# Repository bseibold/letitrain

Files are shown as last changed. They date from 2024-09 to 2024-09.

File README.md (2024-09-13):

# Let it rain

An ESP32 board intended for use with TL-136 level sensors

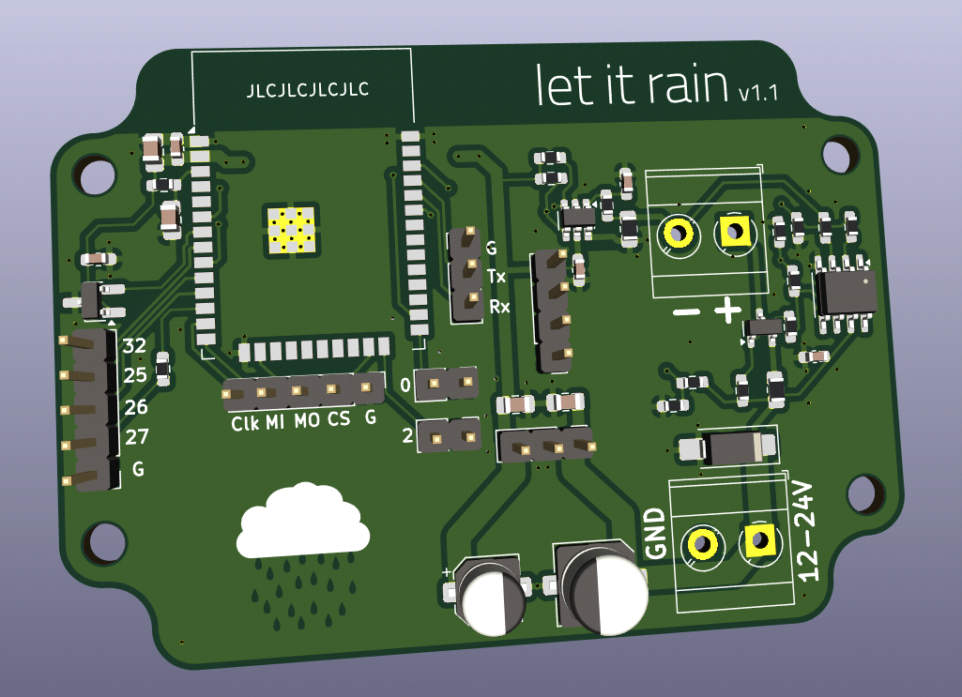
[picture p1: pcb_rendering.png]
Rendering of the PCB


## Status

Version 1 was built and is running well.

## Description

The sensor officially requires 24V, but in practice it runs well down to about 7V.
An op-amp is used to limit the current through the sensor and protect the ADC in case
of a short-circuit. The bias current of the op-amp has a small but measureable effect,
however the voltage measured by the ADC is still very linear to the current through the
sensor.

## Software

The board can be used with ESPHome, see [esphome.yaml](esphome.yaml) for an example configuration.

## BOM

 - 1x TL-136 differential pressure level sensor
 - 1x ESP32-WROOM-32x, can be any variant with the same footprint
 - 1x MCP3421 ADC converter
 - 1x OP07 Operational Amplifier
 - 1x MCP9700B temperature sensor (optional)
 - 1x DC-DC module with 780x compatible pins and 3.3V output. Must support 12-18V input

 - MLCC capacitors 0603, X5R or X7R, at least 6.3V
   - 5x 100nF (C1, C2, C3, C5, C6)
   - 1x 1µF (C2)
   - 2x 10µF (C4, C9)
 - MLCC capacitors 0603, X5R or X7R, at least 25V (better 50V)
   - 1x 100nF (C7)
   - 1x 1µF (C8)
 - 1x Polymer capacitor 5.0mm, at least 6.3V, 22µF (C10)
 - 1x Polymer capacitor 6.3mm, at least 25V (better 50V), 10µF (C11)
 - 1x Bidirectional TSV diode, SMA, voltage slightly above max. supply voltage (D1, optional)
 - 1x Pin header 0,1" 1x3 Pins (J3)
 - 1x BSS84 P-Channel Enhancement MOSFET (Q1)
 - 8x Resistor 0603, 10kOhm (R1, R3, R4, R9, R10, R11, R12, R15)
 - 2x Resistor 0603, 47kOhm (R2, R13)
 - 3x Resistor 0603, 1kOhm (R5, R6, R7)
 - 1x Resistor 0805, 100Ohm, high precision (R8)
 - 1x Resistor 0805, 33Ohm (R14)

Optional pin headers are omitted. They are intended for later reuse of spare PCBs.

The enclosure is an RL6115 from Hammond Manufacturing.

## Changelog

### Version 1.1

- Made more room for DC-DC module, it was a tight fit next to the capacitors
- Rotated TSV diode so that silkscreen is correct for unidirectional diodes
- Changed temperature sensor from MCP9701 to MCP9700B, changed footprint from SC70-5 to SOT23-3
- Some cosmetic fixes
- Marked optional stuff as DNP

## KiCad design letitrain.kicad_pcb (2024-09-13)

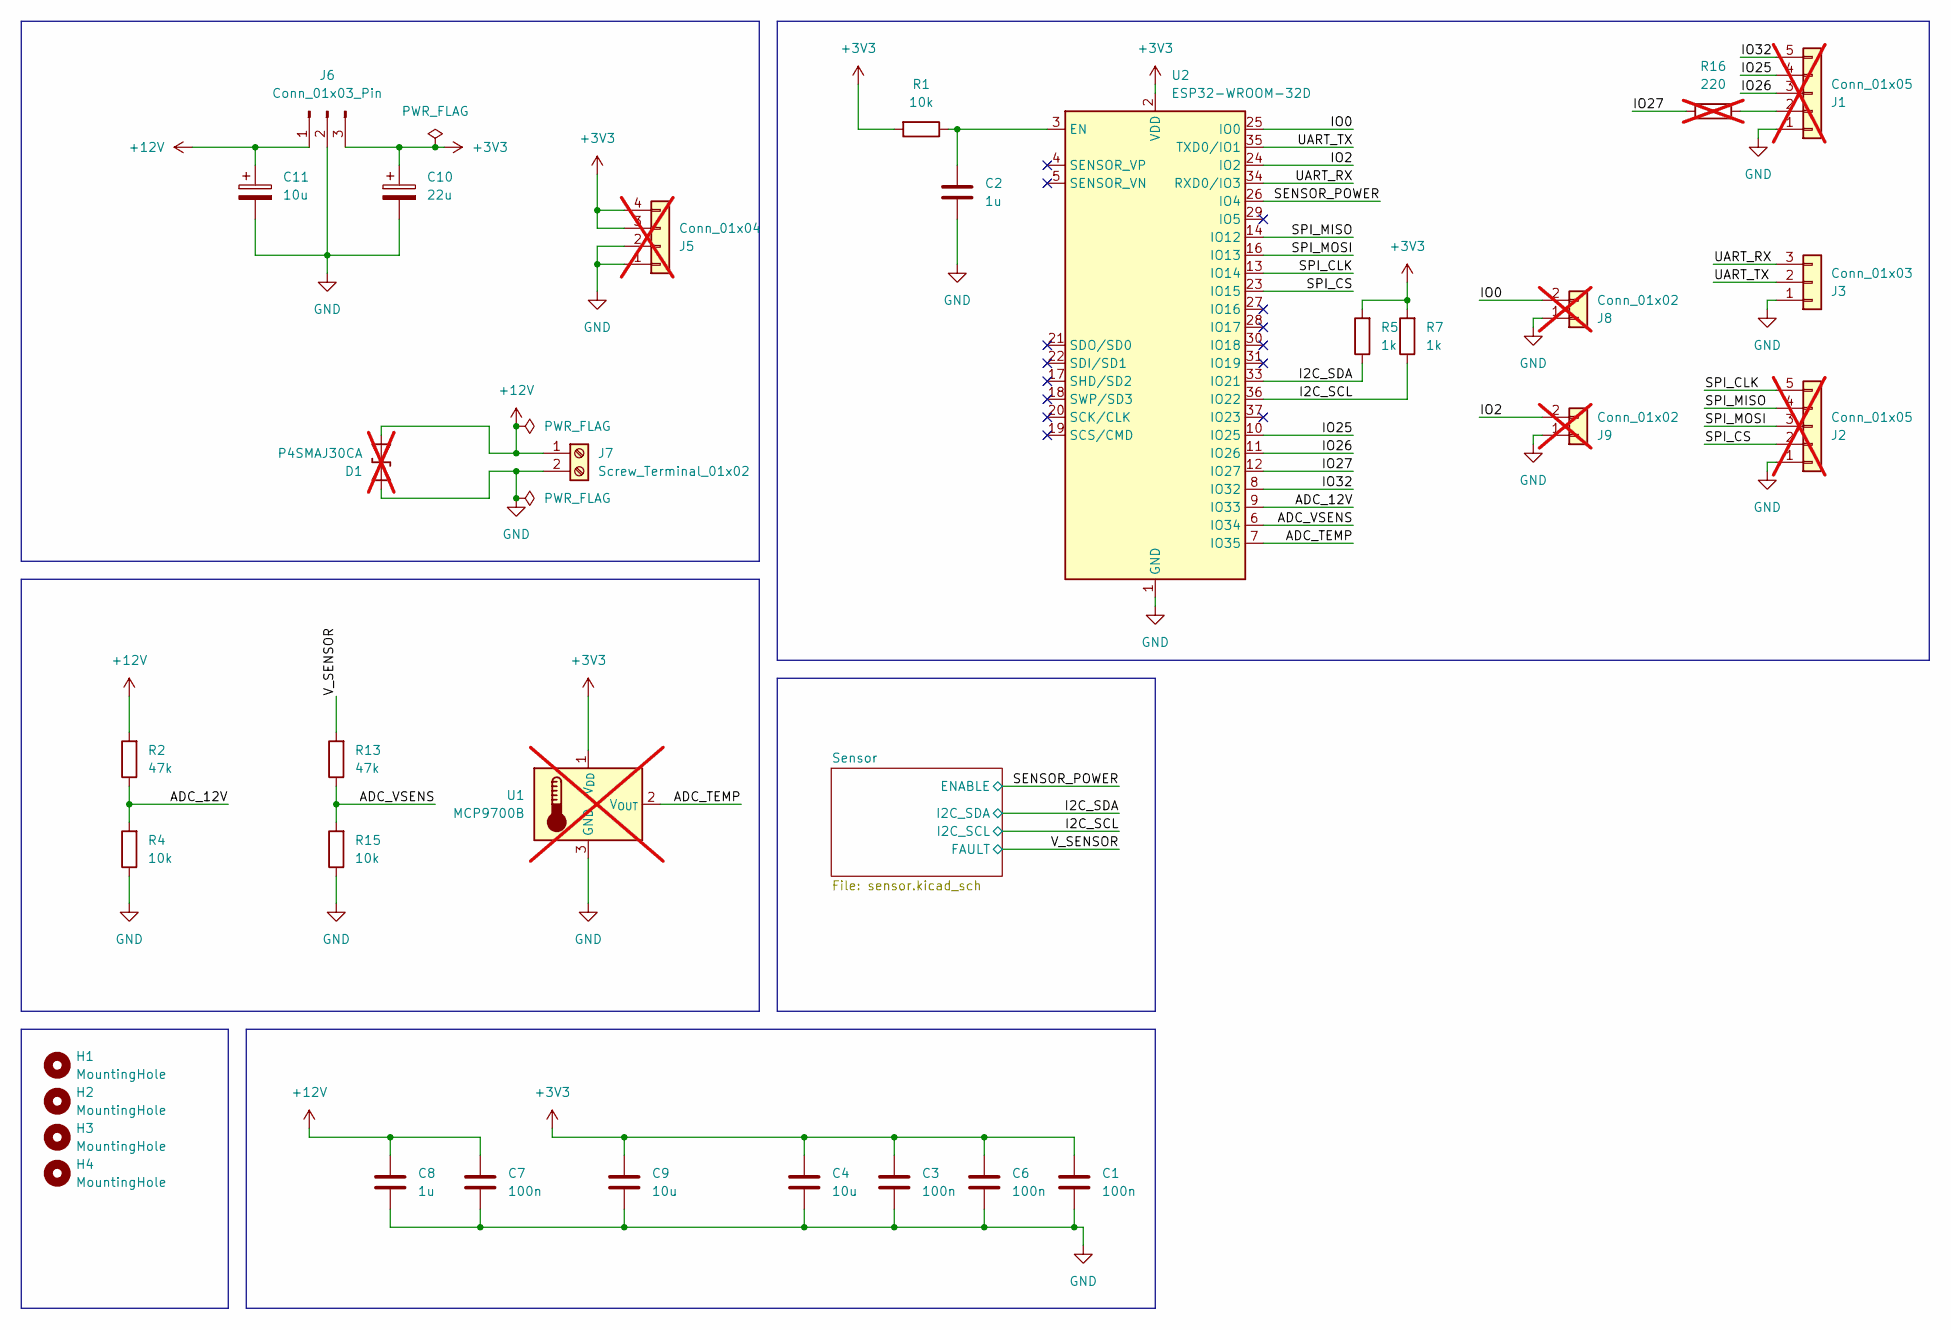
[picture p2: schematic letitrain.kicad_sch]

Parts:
C1, C3, C6, C7: 100n; C_0603_1608Metric_Pad1.08x0.95mm_HandSolder
C2, C8: 1u; C_0805_2012Metric_Pad1.18x1.45mm_HandSolder
C4, C9: 10u; C_0805_2012Metric_Pad1.18x1.45mm_HandSolder
C10: 22u; CP_Elec_5x5.8
C11: 10u; CP_Elec_6.3x5.8
D1: P4SMAJ30CA; D_SMA_Handsoldering; not fitted
H1, H2, H3, H4: MountingHole; MountingHole_3.2mm_M3
J1, J2: Conn_01x05; PinHeader_1x05_P2.54mm_Vertical; not fitted
J3: Conn_01x03; PinHeader_1x03_P2.54mm_Vertical
J5: Conn_01x04; PinHeader_1x04_P2.54mm_Vertical; not fitted
J6: Conn_01x03_Pin; PinHeader_1x03_P2.54mm_Vertical
J7: Screw_Terminal_01x02; TerminalBlock_MetzConnect_Type073_RT02602HBLU_1x02_P5.08mm_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
J8, J9: Conn_01x02; PinHeader_1x02_P2.54mm_Vertical; not fitted
R1, R4, R15: 10k; R_0603_1608Metric_Pad0.98x0.95mm_HandSolder
R2, R13: 47k; R_0603_1608Metric_Pad0.98x0.95mm_HandSolder
R5, R7: 1k; R_0603_1608Metric_Pad0.98x0.95mm_HandSolder
R16: 220; R_0603_1608Metric_Pad0.98x0.95mm_HandSolder; not fitted
U1: MCP9700B; SOT-23_Handsoldering; not fitted
U2: ESP32-WROOM-32D

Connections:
+3V3: C1.1, C3.1, C4.1, C6.1, C9.1, C10.1, J5.3, J5.4, J6.3, R1.2, R5.2, R7.2, U1.1 (V_{DD}), U2.2 (VDD); also elsewhere on the board
+12V: C7.1, C8.1, C11.1, D1.1 (A1), J6.1, J7.1, R2.2; also elsewhere on the board
/ADC_12V: R2.1, R4.2, U2.9 (IO33)
/ADC_TEMP: U1.2 (V_{OUT}), U2.7 (IO35)
/ADC_VSENS: R13.1, R15.2, U2.6 (IO34)
/I2C_SCL: R7.1, U2.36 (IO22); also elsewhere on the board
/I2C_SDA: R5.1, U2.33 (IO21); also elsewhere on the board
/IO0: J8.2, U2.25 (IO0)
/IO2: J9.2, U2.24 (IO2)
/IO25: J1.4, U2.10 (IO25)
/IO26: J1.3, U2.11 (IO26)
/IO27: R16.2, U2.12 (IO27)
/IO32: J1.5, U2.8 (IO32)
/SENSOR_POWER: U2.26 (IO4); also elsewhere on the board
/SPI_CLK: J2.5, U2.13 (IO14)
/SPI_CS: J2.2, U2.23 (IO15)
/SPI_MISO: J2.4, U2.14 (IO12)
/SPI_MOSI: J2.3, U2.16 (IO13)
/UART_RX: J3.3, U2.34 (RXD0/IO3)
/UART_TX: J3.2, U2.35 (TXD0/IO1)
/V_SENSOR: R13.2; also elsewhere on the board
GND: C1.2, C2.2, C3.2, C4.2, C6.2, C7.2, C8.2, C9.2, C10.2, C11.2, D1.2 (A2), J1.1, J2.1, J3.1, J5.1, J5.2, J6.2, J7.2, J8.1, J9.1, R4.1, R15.1, U1.3 (GND), U2.1 (GND), U2.15 (GND), U2.38 (GND), U2.39 (GND); also elsewhere on the board
unnamed: J1.2, R16.1
unnamed: C2.1, R1.1, U2.3 (EN)

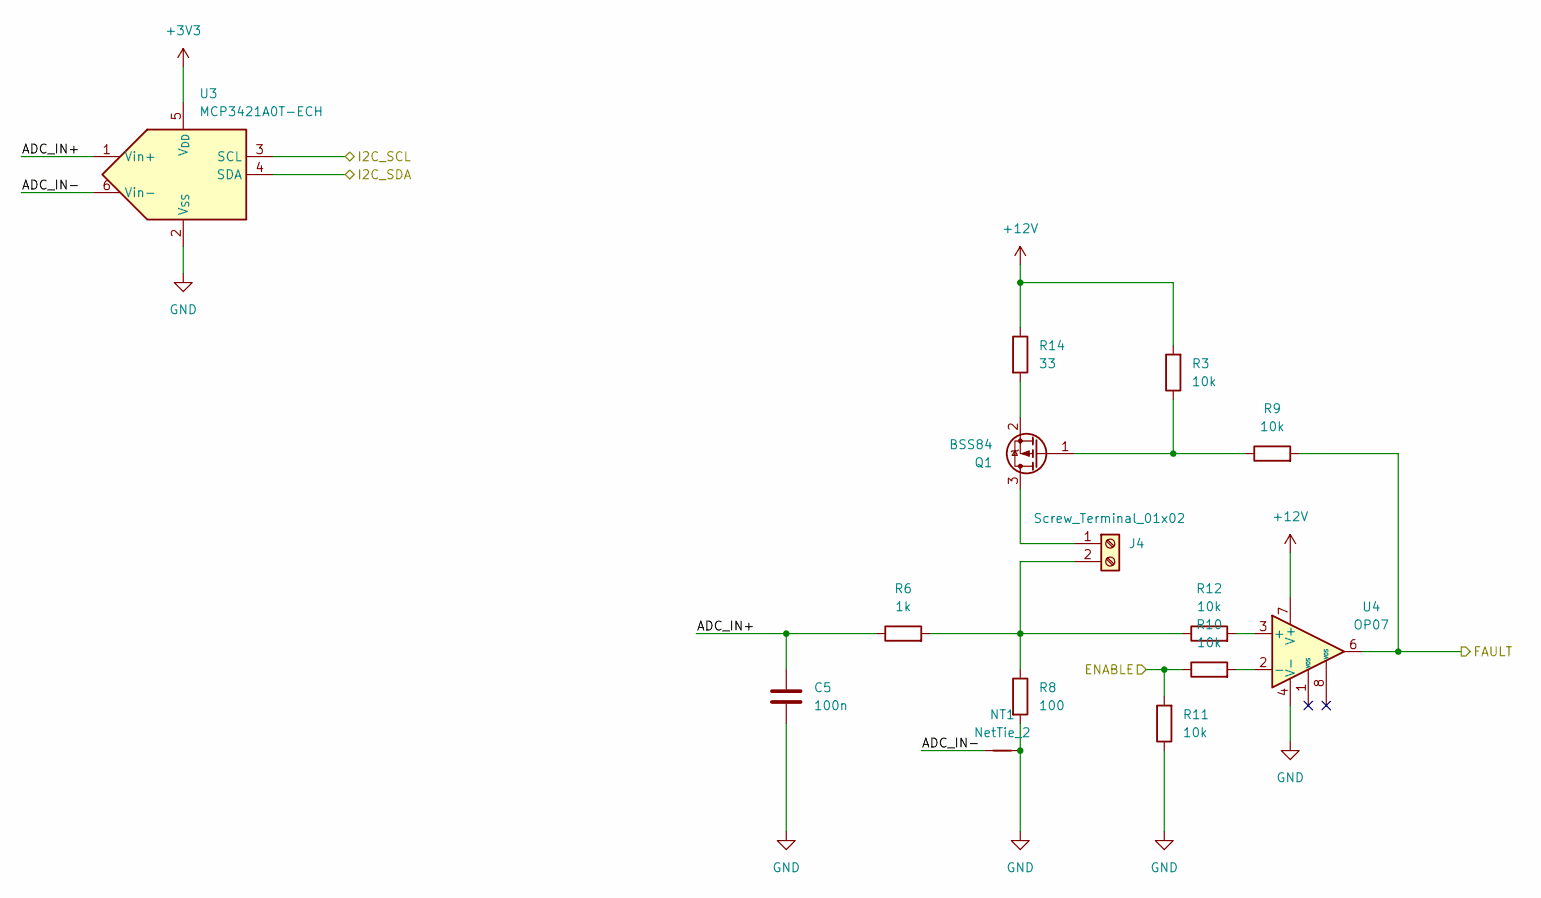
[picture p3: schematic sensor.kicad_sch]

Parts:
C5: 100n; C_0603_1608Metric_Pad1.08x0.95mm_HandSolder
J4: Screw_Terminal_01x02; TerminalBlock_MetzConnect_Type073_RT02602HBLU_1x02_P5.08mm_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
NT1: NetTie_2; NetTie-2_SMD_Pad0.5mm
Q1: BSS84; SOT-23
R3, R9, R10, R11, R12: 10k; R_0603_1608Metric_Pad0.98x0.95mm_HandSolder
R6: 1k; R_0603_1608Metric_Pad0.98x0.95mm_HandSolder
R8: 100; R_0805_2012Metric_Pad1.20x1.40mm_HandSolder
R14: 33; R_0805_2012Metric_Pad1.20x1.40mm_HandSolder
U3: MCP3421A0T-ECH; SOT-23-6
U4: OP07; SO-8_3.9x4.9mm_P1.27mm

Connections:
+3V3: U3.5 (V_{DD}); also elsewhere on the board
+12V: R3.2, R14.1, U4.7 (V+); also elsewhere on the board
/I2C_SCL: U3.3 (SCL); also elsewhere on the board
/I2C_SDA: U3.4 (SDA); also elsewhere on the board
/SENSOR_POWER: R10.1, R11.2; also elsewhere on the board
/Sensor/ADC_IN+: C5.2, R6.1, U3.1 (Vin+)
/Sensor/ADC_IN-: NT1.1, U3.6 (Vin-)
/V_SENSOR: R9.2, U4.6; also elsewhere on the board
GND: C5.1, NT1.2, R8.2, R11.1, U3.2 (V_{SS}), U4.4 (V-); also elsewhere on the board
unnamed: J4.1, Q1.3 (D)
unnamed: J4.2, R6.2, R8.1, R12.1
unnamed: Q1.1 (G), R3.1, R9.1
unnamed: Q1.2 (S), R14.2
unnamed: R12.2, U4.3 (+)
unnamed: R10.2, U4.2 (-)

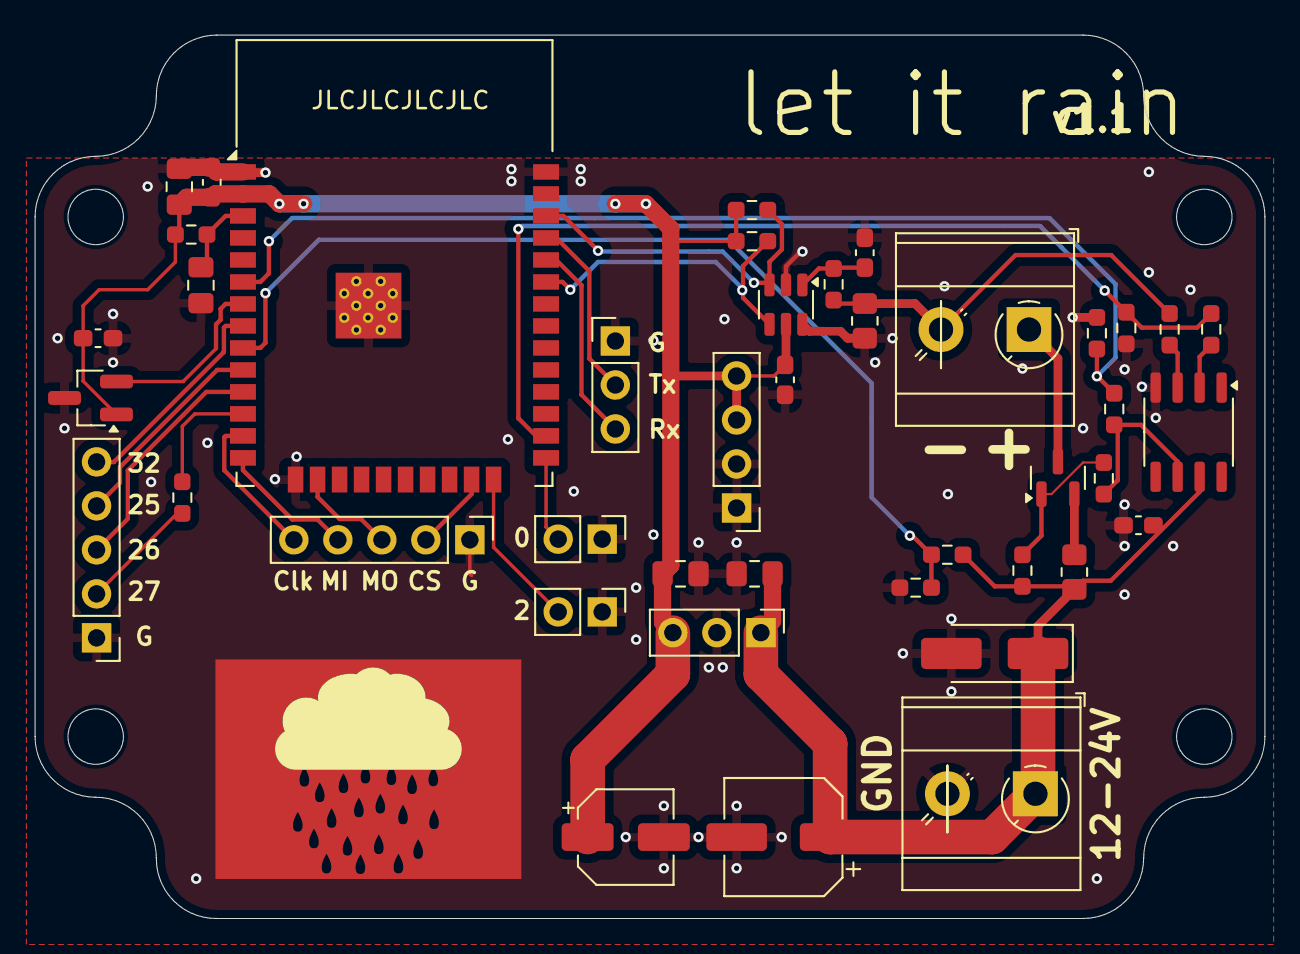
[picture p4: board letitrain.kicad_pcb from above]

Board: 2 copper layers, 71.0 x 51.0 mm, 47 parts (0 on the bottom side), 32 nets.

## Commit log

2024-08-31 Add v1
    [letitrain-B_Cu.gbl, letitrain-B_Mask.gbs, letitrain-B_Paste.gbp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]
2024-09-13 Update to v1.1
    [letitrain.kicad_pcb, letitrain.kicad_sch]
2024-09-13 Add enclosure

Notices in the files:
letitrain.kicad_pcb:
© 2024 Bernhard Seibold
